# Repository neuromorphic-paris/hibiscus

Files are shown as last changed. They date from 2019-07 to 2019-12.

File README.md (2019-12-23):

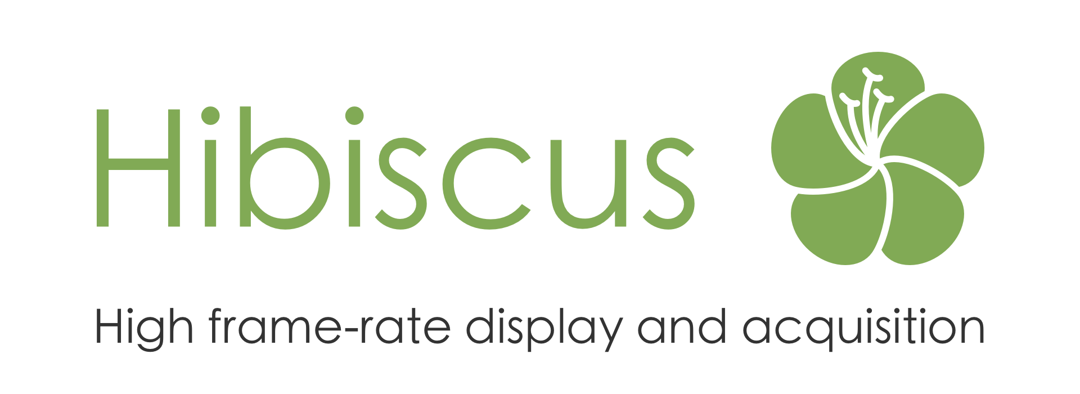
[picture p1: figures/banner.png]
banner


Hibiscus bundles tools to build a complete psychophysics platform on top of hummingbird. It is meant for a Jetson TX1 and a Teensy 3.5.

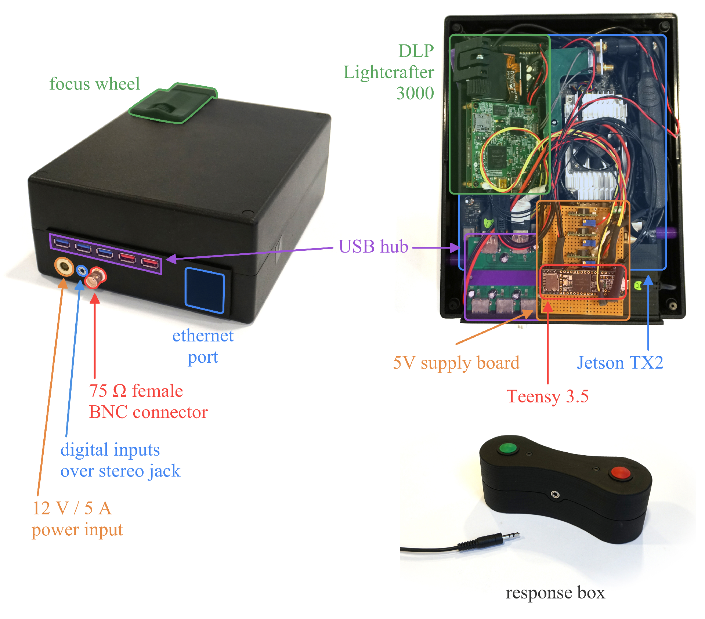
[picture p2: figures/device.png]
device


# parts

3D models of the Hibiscus components can be found in the *parts* directory, in STL format:
- *parts/box/* contains 3D models of the printable components required to assemble an Hibiscus box, in STL format. *parts/box/box.step* contains the whole assembly, and can be used as a reference to assemble it.
- *parts/optical_plate/* contains 3D models of the components of a box-less Hibiscus system, designed to be placed on a metric optical plate. *parts/optical_plate/optical_plate.step* contains the whole assembly, and can be used as a reference to assemble it.
- *parts/response-box/* provides the 3D models of the response box. *parts/response_box/response_box.step* contains the whole assembly, and can be used as a reference to assemble it.

# connect to the Jetson

1. Set up your ethernet configuration as follows:
  - IP address: `20.20.20.100`
  - Mask: `255.255.255.0`
  - Gateway: leave blank

2. Run the command:
```
ssh nvidia@20.20.20.99
```
The password is `nvidia`.

If you are connected to the same WiFi network as the Jetson, you can use it as well.

# network overview

Once everything is set up, the system will have the following network configuration.

__WiFi__: The Jetson's WiFi uses the default configuration, and is used to connect to the internet for updates, git clones... The *System Settings app* can be used to connect to new networks.
- Typical network: `192.168.1.*`
- Jetson IP address: given by the WiFi router.

__Ethernet__: The Jetson's ethernet port is used to communicate with other computers during experiments.
- Network: `20.20.20.*` (mask `255.255.255.0`)
- Jetson IP address: `20.20.20.99`
- Network configuration for the experimentalist:
  - IP address: `20.20.20.100`
  - Mask: `255.255.255.0`

__LightCrafter__: The LightCrafter manages a pseudo-network when connected to the Jetson through USB. The default IP must be changed to avoid conflicts with the WiFi network.
- Network: `10.10.10.*` (mask `255.255.255.0`)
- Jetson IP address: `10.10.10.99`
- LightCrafter IP address: `10.10.10.100`

# user guide

## scripts

### do_block.py

`do_block.py` runs the `calibrate` and `record` programs.

```sh
cd /path/to/hummingbird
python3 scripts/do_block.py [options] /path/to/parameters.py
```
Available options:
- `-f`, `--force` overwrites the output file if they exist.
- `-s`, `--skip-calibration` skips the calibration and only records. The calibration file must have been generated beforehand.
- `-g`, `--gpu-message` does not hide the GPU messages.
- `-h`, `--help` shows the help message.

The programs `calibrate` and `record` must be compiled before using the script. Instructions are given by the [programs](#programs) section.

`/path/to/parameters.py` must have the following structure:
```json
{
    "calibration": "/path/to/calibration.json",
    "clips": ["/path/to/first/clip.mp4", "/path/to/second/clip.mp4"],
    "output": "/path/to/output.es",
    "before_fixation_duration": 1200,
    "fixation_duration": 1100,
    "after_fixation_duration": 200,
    "points": [
        [ 34,  34],
        [171,  34],
        [308,  34],
        [ 34, 171],
        [171, 171],
        [308, 171],
        [ 34, 308],
        [171, 308],
        [308, 308]
    ],
    "pattern": [,
        "   #   ",
        "   #   ",
        "   #   ",
        "#######",
        "   #   ",
        "   #   ",
        "   #   "
    ]
}
```

- `"calibration"` is the path to the output calibration file. If this path is not absolute, it is resolved relatively to `/path/to/parameters.py`. If this file already exists, the program stops unless the flag `--force` is added to the arguments.

- `"clips"` is a list of video clip paths. Each non-absolute path in this list is resolved relatively to `/path/to/parameters.py`. The list cannot be empty, but has otherwise no length restriction.

- `"output"` is the path to the output Event Stream file. If this path is not absolute, it is resolved relatively to `/path/to/parameters.py`. If this file already exists, the program stops unless the flag `--force` is added to the arguments.

See [calibrate](#calibrate) for details on the optional parameters `"before_fixation_duration"`, `"fixation_duration"`, `"after_fixation_duration"`, `"points"` and `"pattern"`.

### read_es.py

`read_es.py` reads the binary output of the `record` program (see below) and prints a text-based representation of the data.

```sh
cd /path/to/hummingbird
python3 scripts/read_es.py [options] /path/to/record/output.es
```
Available options:
- `-h`, `--help` shows the help message.

This script requires the python module `eventstream`. Install instructions are available at [https://github.com/neuromorphic-paris/utilities#python](https://github.com/neuromorphic-paris/utilities#python).

## programs

### calibrate

`calibrate` estimates the parameters of the Livetrack to DMD 4 x 4 calibration matrix.
```sh
cd /path/to/hummingbird
./build/release/calibrate [options] output.json
```
Available options:
- `-p parameters.json`, `--parameters parameters.json` sets the calibration parameters. If the parameter is option is not passed, the parameters default to the equivalent *parameters.json* file content:
  ```json
  {
      "before_fixation_duration": 1200,
      "fixation_duration": 1100,
      "after_fixation_duration": 200,
      "points": [
          [ 34,  34],
          [171,  34],
          [308,  34],
          [ 34, 171],
          [171, 171],
          [308, 171],
          [ 34, 308],
          [171, 308],
          [308, 308]
      ],
      "pattern": [
          "   #   ",
          "   #   ",
          "   #   ",
          "#######",
          "   #   ",
          "   #   ",
          "   #   "
      ]
  }
  ```
  Only fields different from the defaults need to be specified. The durations are expressed in milliseconds. There must be at least four points (results are more accurate with more points. The pattern must have an odd number of rows and columns, and must contain only `'#'` and `' '` characters (representing on and off pixels, respectively).
- `-i [ip]`, `--ip [ip]` sets the LightCrafter IP address (defaults to `"10.10.10.100"`).
- `-f`, `--force` overwrites the output file if it exists.
- `-h`, `--help` shows the help message.

The generated `output.json` file has the following structure:
```json
{
    "points": [
        [ 34,  34],
        [171,  34],
        [308,  34],
        [ 34, 171],
        [171, 171],
        [308, 171],
        [ 34, 308],
        [171, 308],
        [308, 308]
    ],
    "left": {
        "matrix": [
            -0.000500992,   0.00269572, -0.00103148,  274.081,
             -0.00058359,  -0.00140402,  0.00189917,  212.388,
             5.27852e-19, -8.10961e-19, 1.06127e-18, 0.273093,
             3.89546e-07,  7.84538e-07, 2.16504e-07, 0.458227
        ],
        "reprojection_errors": [
            3.63763,
            4.67781,
            9.13678,
             6.2297,
            9.15647,
            7.30571,
            8.89996,
            9.15647,
            9.15507
        ]
    },
    "right": {
        "matrix": [
             0.00021368,   0.00266984, -0.000797397,   292.963,
            -0.00191981, -0.000169172,  4.59669e-05,   10.0208,
            4.17353e-08,  3.80498e-08,  -4.9549e-06, -0.476671,
            6.41801e-08, -1.92392e-07,   1.7655e-08,  0.396832
        ],
        "reprojection_errors": [
            5.35004,
            3.27579,
            5.49818,
            2.27209,
             4.0961,
            2.70487,
            5.49482,
            5.49901,
            5.49899
        ]
    }
}
```
The reprojection errors are expressed in screen pixels.

### record

`record` plays a list of stimuli and records precise timings.
```sh
cd /path/to/hummingbird
./record [options] /path/to/calibration.json /path/to/first/clip.mp4 [/path/to/second/clip.mp4...] output.es
```
Available options:
- `-f`, `--force` overwrites the output file if it exists.
- `-d`, `--duration` sets the inhibition duration in microseconds (defaults to `500000`). Button pushes during this duration after a video start are not accounted for.
- `-b [frames], --buffer [frames]` sets the number of frames buffered (defaults to 64). The smaller the buffer, the smaller the delay between videos. However, small buffers increase the risk to miss frames.
- `-i [ip]`, `--ip [ip]` sets the LightCrafter IP address (defaults to `"10.10.10.100"`).
- `-h`, `--help` shows the help message.

The generated `output.es` file is an [Event Stream](https://github.com/neuromorphic-paris/event_stream) containing generic events. Each generic event's payload contains at least one byte encoding the type in ASCII. Some types are associated with more data, as follows:

- `bytes[0] == 'a'` (respectively `bytes[0] == 'b'`): left (respectively right) eye position, the following twenty-four bytes encode the eye position as double floats in screen coordinates, and the pupil's ellipse's major and minor axis as uint32 in camera pixels (with a `8192` scale factor):
  ```cpp
  x = double(byte[1]
      | (byte[2] << 8)
      | (byte[3] << 16)
      | (byte[4] << 24)
      | (byte[5] << 32)
      | (byte[6] << 40)
      | (byte[7] << 48)
      | (byte[8] << 56))
  y = double(byte[9]
      | (byte[10] << 8)
      | (byte[11] << 16)
      | (byte[12] << 24)
      | (byte[13] << 32)
      | (byte[14] << 40)
      | (byte[15] << 48)
      | (byte[16] << 56))
  major_axis = (byte[17] | (byte[18] << 8) | (byte[19] << 16) | (byte[20] << 24)) / 8192
  minor_axis = (byte[21] | (byte[22] << 8) | (byte[23] << 16) | (byte[24] << 24)) / 8192
  ```
- `bytes[0] == 'c'`: LiveTrack synchronisation linear interpolation executed, the following sixteen bytes encode `t` and `u` (respectively the Teensy and LiveTrack timestamps):
  ```cpp
  t = byte[1]
      | (byte[2] << 8)
      | (byte[3] << 16)
      | (byte[4] << 24)
      | (byte[5] << 32)
      | (byte[6] << 40)
      | (byte[7] << 48)
      | (byte[8] << 56)
  u = byte[9]
     | (byte[10] << 8)
     | (byte[11] << 16)
     | (byte[12] << 24)
     | (byte[13] << 32)
     | (byte[14] << 40)
     | (byte[15] << 48)
     | (byte[16] << 56)
  ```
  The LiveTrack timestamps are converted to Teensy timestamps at runtime. `c` events can be used after recording to achieve a better, offline reconstruction of the clock conversion.
- `bytes[0] == 'f'`: frame displayed, the following four bytes encode its index in the current clip:
  ```cpp
  index = byte[1] | (byte[2] << 8) | (byte[3] << 16) | (byte[4] << 24)
  ```
- `bytes[0] == 'l'`: left button pressed, no extra bytes.
- `bytes[0] == 'r'`: right button pressed, no extra bytes.
- `bytes[0] == 's'`: new clip start, the following four bytes encode its index:
:
  ```cpp
  index = byte[1] | (byte[2] << 8) | (byte[3] << 16) | (byte[4] << 24)
  ```
- `bytes[0] == 'w'`: warning, the extra bytes encode the error message in ASCII.

### monitor_teensy

`monitor_teensy` displays the events timestamped by the teensy. It is meant as a debug tool to make sure that everything is properly connected.

```sh
cd /path/to/hummingbird
./build/release/monitor_teensy
```

# setup an out-of-the-box Jetson TX1

1. connect a screen, keyboard and mouse to the Jetson board. The LightCrafter can be used as a screen.

2. flash the Jetson TX1 with the latest release available (see https://developer.nvidia.com/embedded/linux-tegra-archive). The __L4T 28.2__ was used here. This step requires a Linux computer. The following commands were used on a Debian 9 machine (with *sudo* installed):
```sh
L4T_RELEASE_PACKAGE=Tegra210_Linux_R28.2.0_aarch64.tbz2
SAMPLE_FS_PACKAGE=Tegra_Linux_Sample-Root-Filesystem_R28.2.0_aarch64.tbz2
wget https://developer.nvidia.com/embedded/dlc/l4t-jetson-tx1-driver-package-28-2-ga -O ${L4T_RELEASE_PACKAGE}
wget https://developer.nvidia.com/embedded/dlc/l4t-sample-root-filesystem-28-2-ga -O ${SAMPLE_FS_PACKAGE}
sudo tar xpf ${L4T_RELEASE_PACKAGE}
cd Linux_for_Tegra/rootfs/
sudo tar xpf ../../${SAMPLE_FS_PACKAGE}
cd ..
sudo ./apply_binaries.sh
```
Then (from the Quick Start Guide):
    -  Ensure your Linux host system is connected to the Jetson Developer Kit's
      micro-USB port using a USB cable.
    - Put your Jetson Developer Kit into "USB Recovery Mode" (RCM). In all
      cases, press and hold the "REC" (force recovery) button for the duration
      of this step. Then, if your Jetson Developer Kit is powered off, press
      and release the "POWERBTN" button, or if your Jetson Developer Kit is
      already powered on, press and release the "RST" (reset) button. Finally,
      release the "REC" button.
    - Install (flash) the L4T release onto the Jetson Developer Kit, by
      executing the following command on your Linux host system:
    ```
    sudo ./flash.sh jetson-tx1 mmcblk0p1
    ```
If the error `/dev/loop0 is not block device` is encountered when flashing, run `sudo losetup --find` and retry.

3. all the following steps apply to the Jetson board. Log in with:
```
login: nvidia
password: nvidia
```

4. with the *System Settings* app:
  - (optionnal) change the keyboard map (*Keyboard* section)
  - setup the Wi-Fi connection (*Network* section)
  - prevent the screen from turning off (*Brightness & Lock* section)
  - switch to automatic login on boot for the *nvidia* user (*User accounts* section)
  - auto-hide the side bar (*Appearance* section, *Behavior* tab)

5. enable the *universe* packages by uncommenting the four lines 17 to 20 in */etc/apt/sources.list*
```
sudo gedit /etc/apt/sources.list
```

6. upgrade the packages
```sh
sudo apt update
sudo apt upgrade
sudo apt autoremove
```

7. enable the network time synchronization
  - Install the background synchronization manager
```sh
sudo apt install ntp
```
  - Edit */etc/ntp.conf*
```
sudo gedit /etc/ntp.conf
```
Add the following lines at the beginning of the file:
```
tinker panic 0
server 134.157.180.254
```
  - Reboot
  ```
  sudo reboot
  ```

8. install *hummingbird*'s C++ apps dependencies, and build them:
```sh
cd ~
# copy the hibiscus directory (manual copy for  now, git clone eventually)
cd hibiscus/third_party/hummingbird
sudo apt install premake4
sudo apt install ffmpeg
sudo apt install libgstreamermm-1.0-dev gstreamer1.0-plugins-good gstreamer1.0-plugins-bad gstreamer1.0-libav
sudo apt install libglfw3-dev
premake4 gmake
cd build
make
```

9. change the LightCrafter IP address:
  - Connect the LightCrafter's USB cable
  - Click on the WiFi icon in the top bar, and select connection information. Find the LightCrafter current IP address (here, the LightCrafter appears as *Wired Connection 2*, the Jetson has the address `192.168.1.99`, and the LightCrafter answers to ping at `192.168.1.100`)
  - Use the `change_lightcrafter_ip` app to switch the IP to `10.10.10.100`:
```sh
~/hibiscus/third_party/hummingbird/build/release/change_lightcrafter_ip 192.168.1.100 10.10.10.100
```
  - Restart the LightCrafter

10. enable the DMD display for distant sessions by appending to *~/.bashrc*:
```
export DISPLAY=:0.0
```

11. play *test.mp4* to check the installation
```sh
~/hibiscus/third_party/hummingbird/build/release/play -l ~/hibiscus/test.mp4
```
Press `Escape` to quit the app. The command prints debug information to *stderr*. We could not find an easy solution to disable it. A (bad) solution consists in filtering the output with bash, which can be done as follows:
```
{ ~/hibiscus/third_party/hummingbird/build/release/play -l ~/hibiscus/test.mp4 2>&1 1>&3 | grep -vE '(TVMR|NvMMLite|OPENMAX|Allocating)' 1>&2; } 3>&1
```
If you interrupt the app with `Ctrl` `C`, the LightCrafter will remain in high-speed mode. You can run:
```sh
~/hibiscus/third_party/hummingbird/build/release/change_lightcrafter_ip 10.10.10.100 10.10.10.100
```
to manually switch back to default mode. You can also install xdotool:
```sh
sudo apt install xdotool
```
and send an fake Escape keypress to the application from another terminal session:
```sh
xdotool key Escape
```

12. install the code dependencies [Eigen](http://eigen.tuxfamily.org) and [ncurses](https://www.gnu.org/software/ncurses):
```
sudo apt install libeigen3-dev libncursesw5-dev libv4l-dev libjpeg-dev libudev-dev
```

13. replace the content of */etc/network/interfaces* with:
```
source-directory /etc/network/interfaces.d
auto eth0
iface eth0 inet static
address 20.20.20.99
netmask 255.255.255.0
```

14. remove the Chromium desktop icon by appending to *~/.bashrc*:
```
rm -f ~/Desktop/chromium-browser.desktop
```

15. enable non-root access to the Teensy
```sh
sudo usermod -a -G dialout nvidia
```

16. add a udev rule to allow non-root users to read data from the LiveTrack:
```sh
printf 'SUBSYSTEMS=="usb", ATTRS{idVendor}=="0861", ATTRS{idProduct}=="3437", MODE="0660" GROUP="nvidia"\n' | sudo tee '/etc/udev/rules.d/99-livetrack.rules'
```

17. change the wallpaper and disable the file browser auto-open on USB mount:
```sh
sudo gsettings set org.gnome.desktop.background picture-uri file:///home/nvidia/hibiscus/wallpaper.png
sudo sudo gsettings set org.gnome.desktop.media-handling automount-open false
sudo reboot
```

18. install the `eventstream` python module:
```sh
pip3 install numpy
git clone --recursive https://github.com/neuromorphic-paris/utilities.git
cd utilities/bindings/python
python3 setup.py install
```

19. add exFAT support:
```sh
sudo apt install exfat-fuse
sudo apt install exfat-utils
```

20. allow non-root to set the date by adding `nvidia ALL=(ALL) NOPASSWD: /bin/date` to the sudoers configuration
```
sudo visudo
```

# teensy

Hummingbird uses a Teensy 3.5 board. It is responsible for precisely timestamping BNC, DMD and button events, as well as for booting the Jetson on power up. Its pinout is available [here](https://www.pjrc.com/teensy/pinout.html).

## setup

Install the [Arduino Software](https://www.arduino.cc/en/Main/Software) and its [Teensyduino](https://www.pjrc.com/teensy/teensyduino.html) extension. Flash the Teensy 3.5 board with *hibiscus/teensy/teensy.ino*.

## communication protocol

Messages in both directions start with `0x00`. Other instances of `0x00` are escaped, therefore `0x00` always indicates a message start. Likewise, `0xff` indicates a message end.

### jetson to teensy

- Request BNC rise: `0x00 'a' 0xff`
- Request BNC fall: `0x00 'b' 0xff`
- Reset: `0x00 'r' 0xff`

Reset empties the teensy's event fifos.

### teensy to jetson

- BNC rising edge: `0x00 'a' t[0] t[1] t[2] t[3] 0xff`
- BNC falling edge: `0x00 'b' t[0] t[1] t[2] t[3] 0xff`
- DMD half-frame: `0x00 'c' u[0] u[1] u[2] u[3] 0xff`
- DMD trigger rising edge (60 Hz frame boundary): `0x00 'd' t[0] t[1] t[2] t[3] 0xff`
- DMD trigger rising edge (others): `0x00 'e' t[0] t[1] t[2] t[3] 0xff`
- Main loop flush : `0x00 'f' t[0] t[1] t[2] t[3] 0xff`
- Left button pressed: `0x00 'l' t[0] t[1] t[2] t[3] 0xff`
- Right button pressed: `0x00 'r' t[0] t[1] t[2] t[3] 0xff`

`t` is the Arduino's clock time in microseconds (`micros()` output). `u` is the Teensy's tick index.

- if `message[i] == 0x00`, `message[i]` must be replaced with the two bytes `0xaa 0xab`
- if `message[i] == 0xaa`, `message[i]` must be replaced with the two bytes `0xaa 0xac`
- if `message[i] == 0xff`, `message[i]` must be replaced with the two bytes `0xaa 0xad`

Timestamps associated with the observables `d`, `e`, `l` and `r` may be out of order (though ordering is guaranteed between events of the same observable). However, no message sent after a flush message can have a timestamp prior to that flush message's.

# development dependencies

## Debian / Ubuntu

Open a terminal and run:
```sh
sudo apt install premake4 # cross-platform build configuration
sudo apt install clang-format # formatting tool
```

## macOS

Open a terminal and run:
```sh
brew install premake # cross-platform build configuration
brew install clang-format # formatting tool
```

## Windows

Download and install:
- [Visual Studio Community](https://visualstudio.microsoft.com/vs/community/). Select at least __Desktop development with C++__ when asked.
- [git](https://git-scm.com)
- [premake 4.x](https://premake.github.io/download.html). In order to use it from the command line, the *premake4.exe* executable must be copied to a directory in your path. After downloading and decompressing *premake-4.4-beta5-windows.zip*, run from the command line:
```sh
copy "%userprofile%\Downloads\premake-4.4-beta5-windows\premake4.exe" "%userprofile%\AppData\Local\Microsoft\WindowsApps"
```

After changing the code, format the source files by running from the *hibiscus* directory:
```sh
for file in source/*.hpp; do clang-format -i $file; done;
for file in source/*.cpp; do clang-format -i $file; done;
clang-format -i teensy/teensy.ino
```

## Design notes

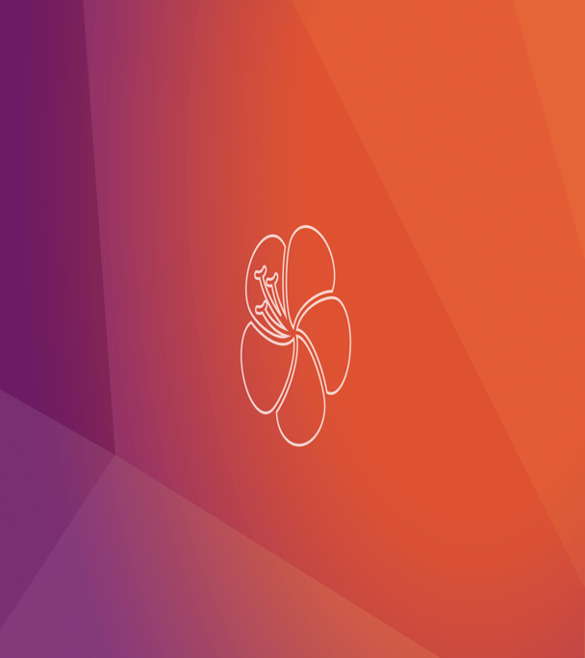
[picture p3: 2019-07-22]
wallpaper.png

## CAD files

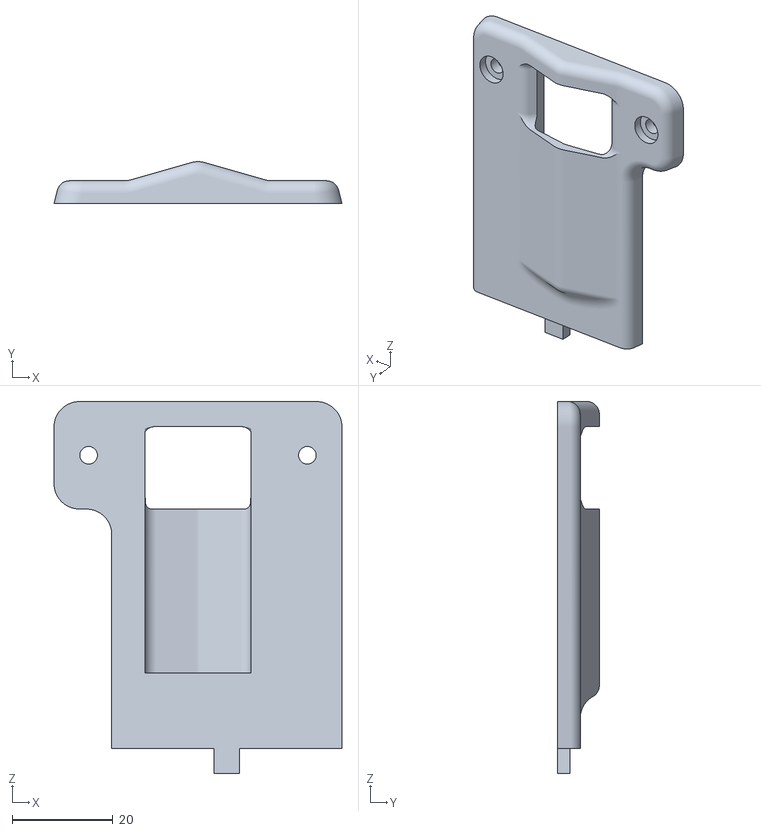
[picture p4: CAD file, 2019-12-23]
parts/box/guard.stl
57.3 x 8.30 x 74.0

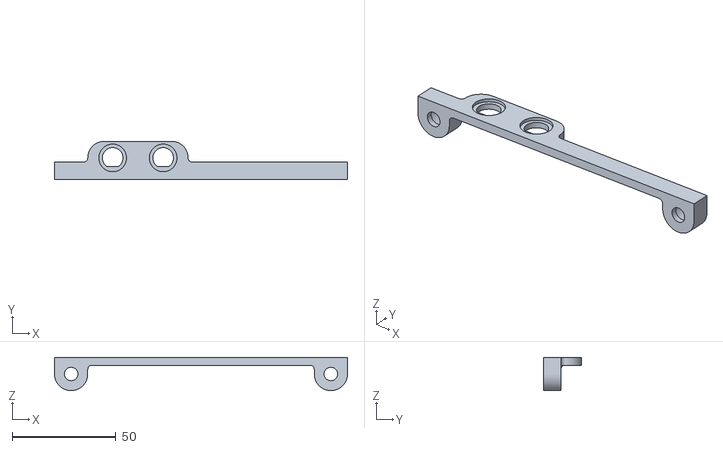
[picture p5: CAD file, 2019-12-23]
parts/optical_plate/bnc_panel.stl
141.0 x 18.5 x 16.0

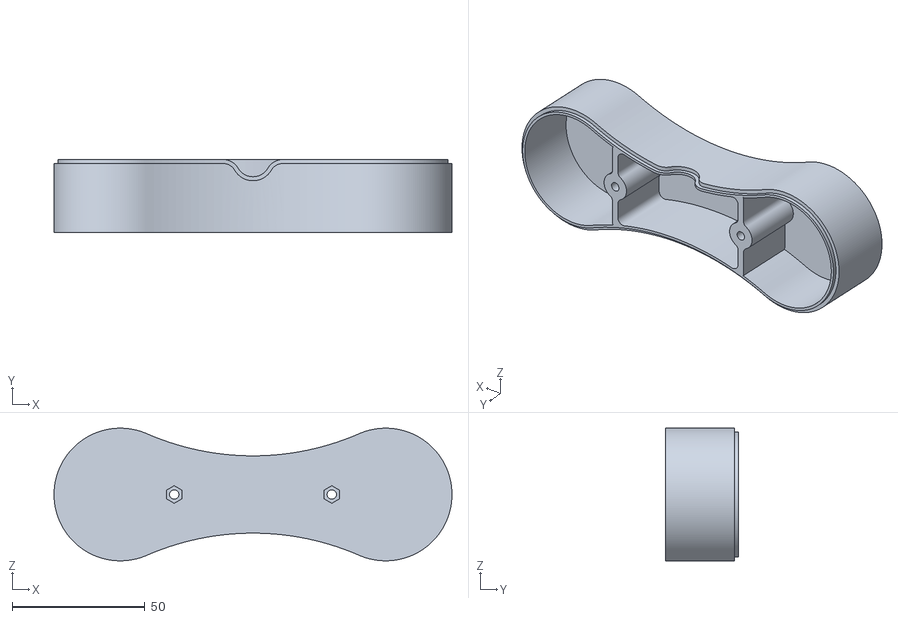
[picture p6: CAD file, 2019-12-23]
parts/response_box/bottom.stl
150.0 x 27.5 x 50.0

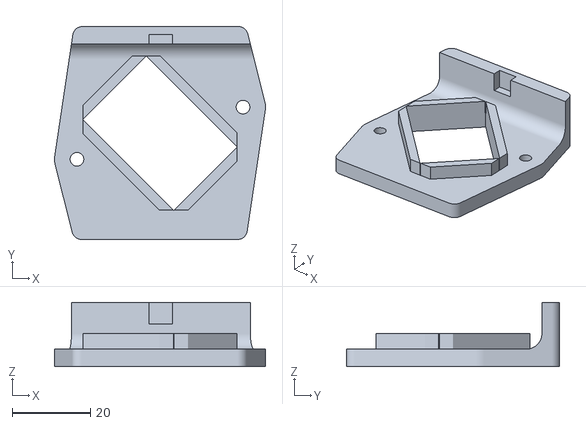
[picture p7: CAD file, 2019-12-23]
parts/box/window.stl
54.0 x 54.5 x 16.5

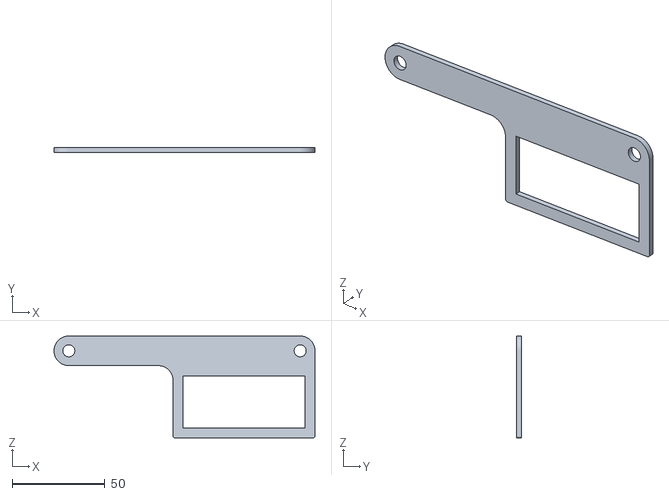
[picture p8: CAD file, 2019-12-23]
parts/optical_plate/teensy_top.stl
141.0 x 2.50 x 55.1

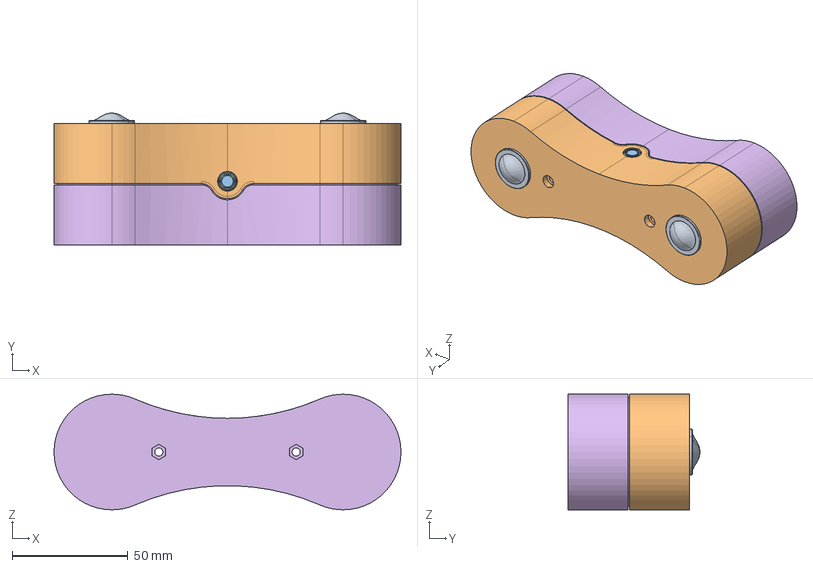
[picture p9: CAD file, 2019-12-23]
parts/response_box/response_box.step
150.0 x 57.0 x 50.0 mm
button x 2
top
jack
jack_nut
button_nut x 2
bottom

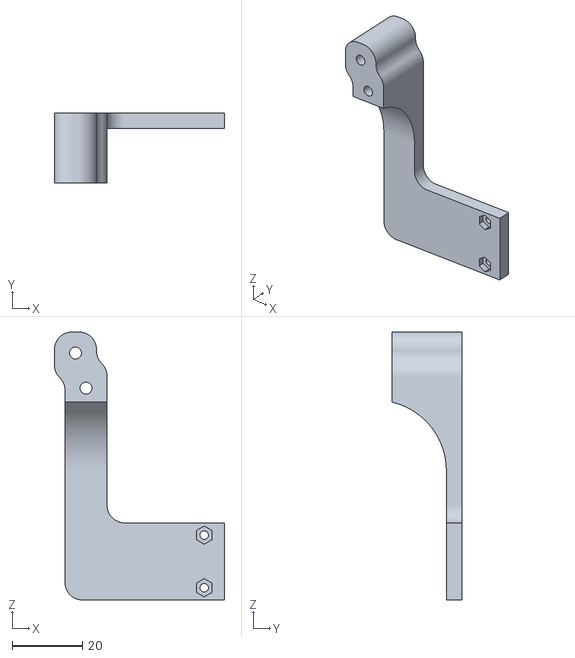
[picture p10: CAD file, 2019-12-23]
parts/box/antenna_holder.stl
48.5 x 20.0 x 76.4

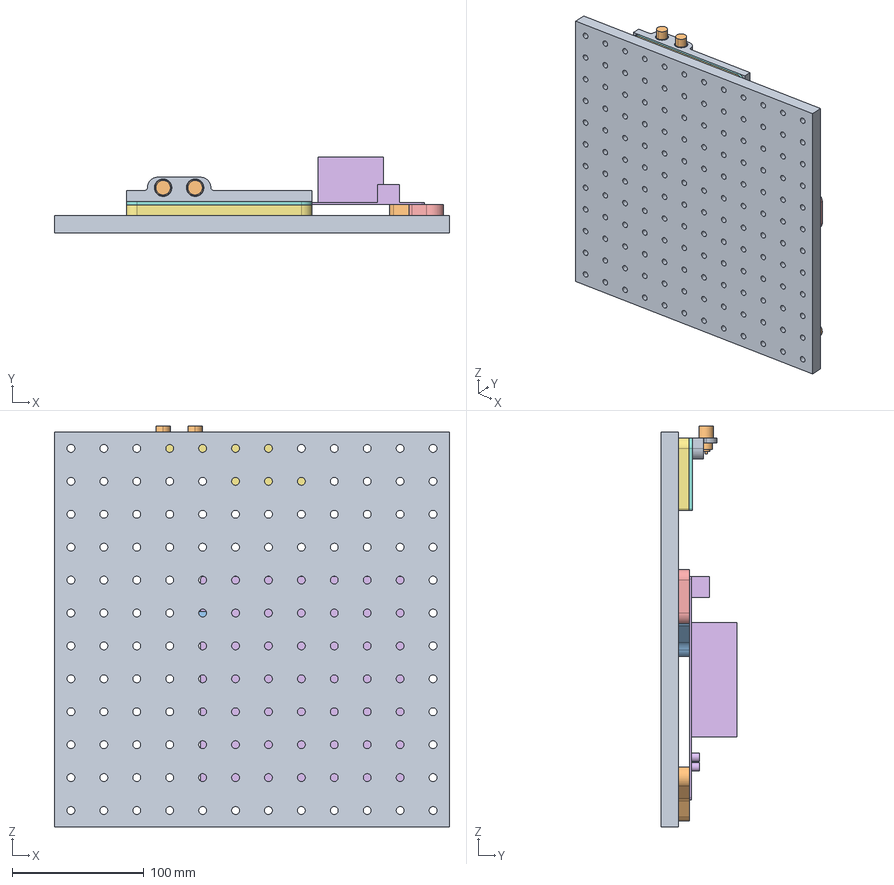
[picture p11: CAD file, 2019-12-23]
parts/optical_plate/optical_plate.step
300.0 x 57.5 x 304.5 mm
plate
adapter
jetson
teensy_base
teensy_top
bnc_panel
bnc x 2

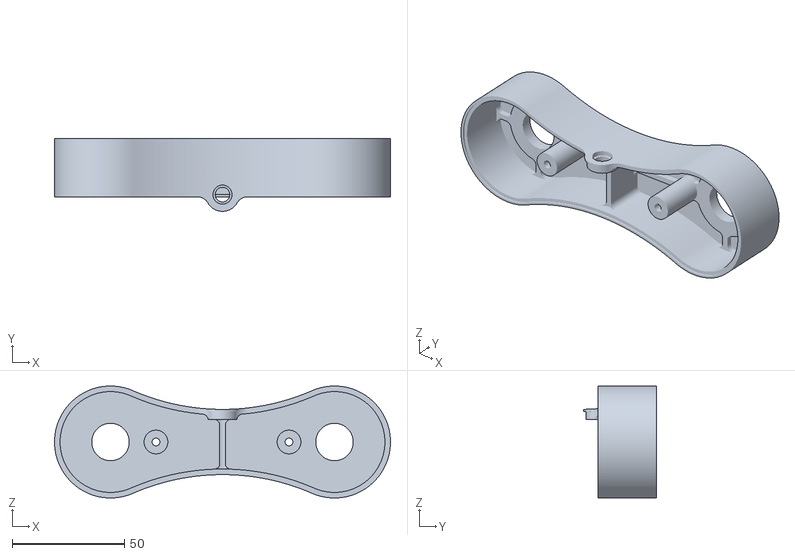
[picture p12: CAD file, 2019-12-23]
parts/response_box/top.stl
150.0 x 32.5 x 50.0

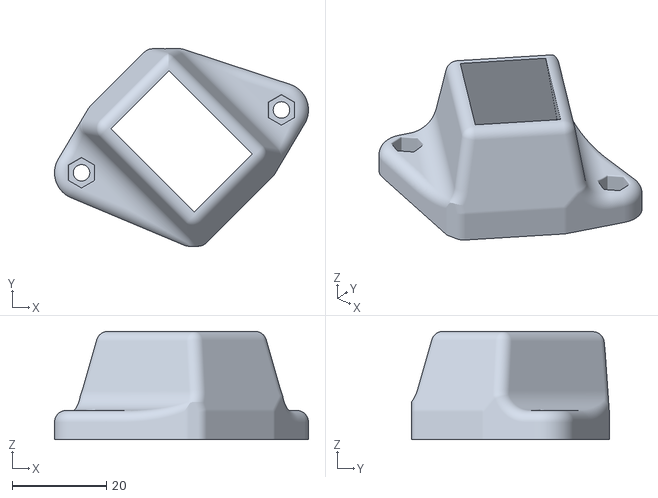
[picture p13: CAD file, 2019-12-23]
parts/box/cone.stl
54.0 x 42.0 x 23.0

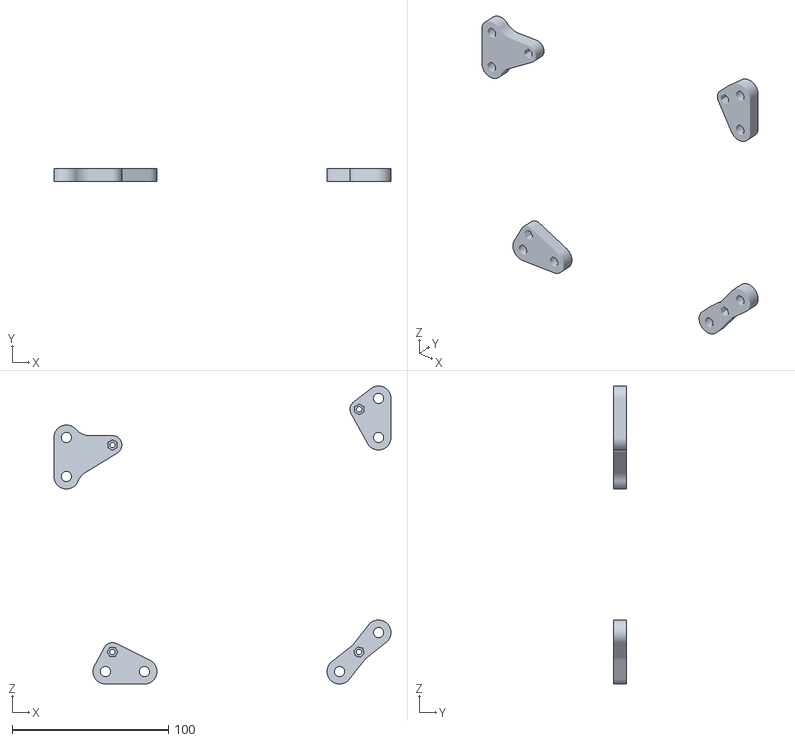
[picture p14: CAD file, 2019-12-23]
parts/optical_plate/adapter.stl
216.0 x 8.50 x 191.0

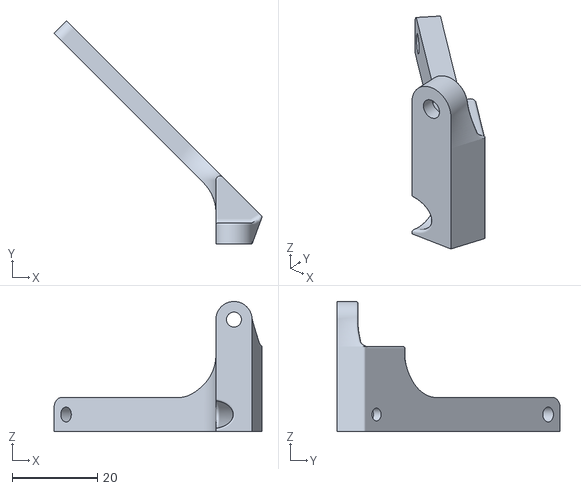
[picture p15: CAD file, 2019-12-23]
parts/box/small_45.stl
48.9 x 52.5 x 30.5

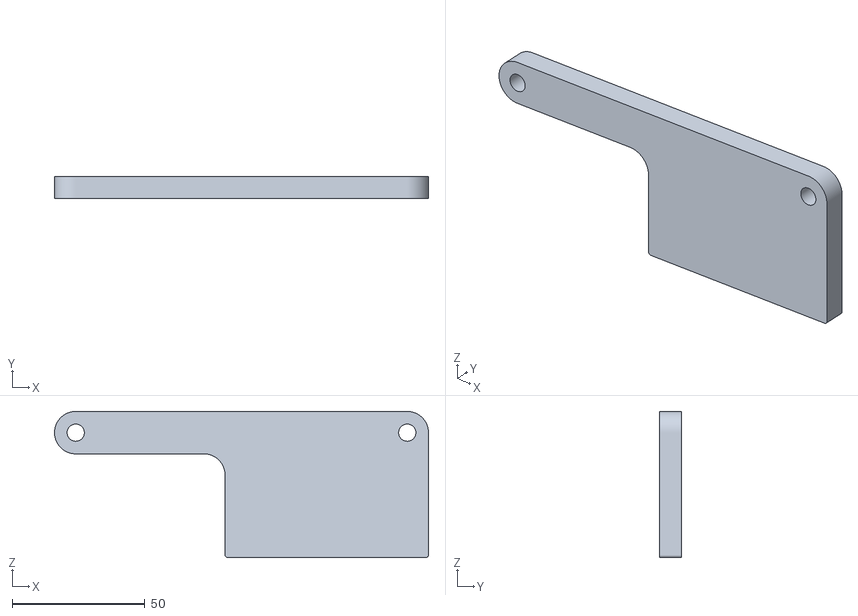
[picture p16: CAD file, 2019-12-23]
parts/optical_plate/teensy_base.stl
141.0 x 8.30 x 55.1

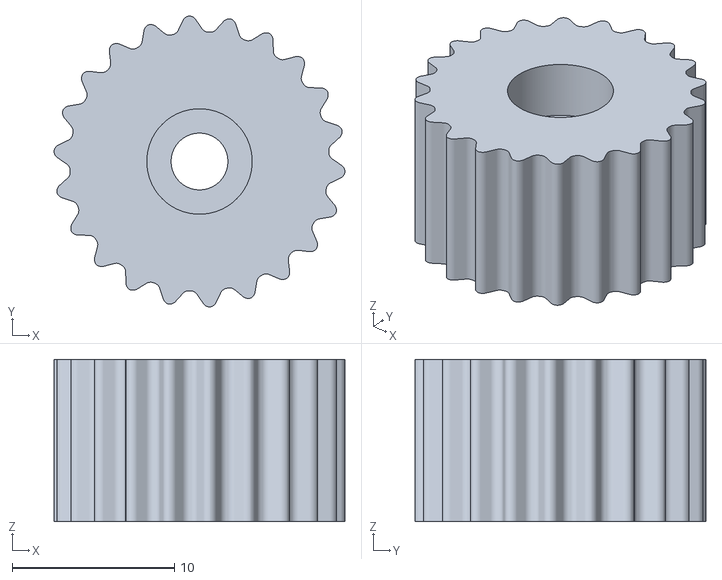
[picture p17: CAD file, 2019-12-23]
parts/box/wheel.stl
18.0 x 18.0 x 10.0

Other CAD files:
parts/box/ethernet.stl
parts/box/slider.stl
parts/box/antenna_spacer.stl
parts/box/chassis.stl
parts/box/large_washer_moon.stl
parts/box/teensee_holder.stl
parts/box/thick_washer_0.stl
parts/box/thick_washer_1.stl
parts/box/thick_washer_2.stl
parts/box/washer.stl

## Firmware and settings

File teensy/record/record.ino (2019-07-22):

const byte bnc_pin = 37;
const byte dmd_pin = 22;
const byte jack_l_pin = 2;
const byte jack_r_pin = 3;
const byte jetson_up_pin = 28;
const byte jetson_switch_on_pin = 29;
const byte led_pin = 13;
const uint32_t tick_half_period = 8333;

/// input represents a signal to watch and timestamp.
struct input {
    const byte id;
    const byte pin;
    const uint32_t debounce_t;
    void (*interrupt_callback)();
    uint8_t tail;
    volatile uint32_t change_t;
    volatile bool is_high;
    volatile uint8_t head;
    volatile uint32_t ts[256];
};

/// interrupt_callback is called whenever the input changes.
/// rising edge changes are notified to the main loop.
void interrupt_callback(input* updated_input) {
    const volatile uint32_t interrupt_t = micros();
    if (updated_input->is_high != (digitalRead(updated_input->pin) == HIGH)) {
        if (updated_input->is_high) {
            updated_input->is_high = false;
        } else {
            updated_input->is_high = true;
            if (interrupt_t - updated_input->change_t > updated_input->debounce_t) {
                updated_input->ts[updated_input->head] = interrupt_t;
                ++updated_input->head;
            }
        }
        updated_input->change_t = interrupt_t;
    }
}

/// inputs lists the input signals.
/// the character 'c' is reserved for clock messages.
input inputs[] = {
    {'d', dmd_pin, 0, d_callback},         // dmd
    {'l', jack_l_pin, 100000, l_callback}, // red button (left)
    {'r', jack_r_pin, 100000, r_callback}, // green button (right)
};
void d_callback() {
    interrupt_callback(&inputs[0]);
}
void l_callback() {
    interrupt_callback(&inputs[1]);
}
void r_callback() {
    interrupt_callback(&inputs[2]);
}

/// read_state stores the globals used by the read function.
struct read_state {
    byte* message;
    const uint32_t message_size;
    uint32_t index;
    bool reading;
    bool escaped;
};

/// read tries to consume a Serial byte and returns true if a new message is ready.
bool read(struct read_state* state) {
    if (Serial.available() > 0) {
        const byte read_byte = Serial.read();
        if (state->reading) {
            byte interpreted_byte;
            bool byte_available = false;
            if (state->escaped) {
                state->escaped = false;
                switch (read_byte) {
                    case 0xab:
                        interpreted_byte = 0x00;
                        byte_available = true;
                        break;
                    case 0xac:
                        interpreted_byte = 0xaa;
                        byte_available = true;
                        break;
                    case 0xad:
                        interpreted_byte = 0xff;
                        byte_available = true;
                        break;
                    default:
                        state->reading = false;
                }
            } else {
                switch (read_byte) {
                    case 0x00:
                        state->index = 0;
                        break;
                    case 0xaa:
                        state->escaped = true;
                        break;
                    case 0xff:
                        state->reading = false;
                        return true;
                    default:
                        interpreted_byte = read_byte;
                        byte_available = true;
                }
            }
            if (byte_available) {
                if (state->index < state->message_size) {
                    state->message[state->index] = interpreted_byte;
                    ++(state->index);
                } else {
                    state->reading = false;
                }
            }
        } else if (read_byte == 0x00) {
            state->reading = true;
            state->escaped = false;
            state->index = 0;
        }
    }
    return false;
}

/// write escapes and writes a null-terminated message to the serial.
void write(const byte* message, const uint32_t size, const bool flush) {
    Serial.write(0x00);
    for (uint8_t index = 0; index < size; ++index) {
        switch (message[index]) {
            case 0x00:
                Serial.write(0xaa);
                Serial.write(0xab);
                break;
            case 0xaa:
                Serial.write(0xaa);
                Serial.write(0xac);
                break;
            case 0xff:
                Serial.write(0xaa);
                Serial.write(0xad);
                break;
            default:
                Serial.write(message[index]);
        }
    }
    Serial.write(0xff);
    if (flush) {
        Serial.send_now();
    }
}

/// send generates and writes a message.
void send(const byte type, const uint32_t t, const bool flush) {
    byte message[5] = {
        type, (byte)(t & 0xff), (byte)((t >> 8) & 0xff), (byte)((t >> 16) & 0xff), (byte)((t >> 24) & 0xff)};
    write(message, sizeof(message), flush);
}

/// state variables
byte read_message[1];
read_state state = {read_message, sizeof(read_message), 0, false, false};
uint32_t previous_d_t = 0;
bool frame_boundary = false;
uint32_t tick = 0;
uint32_t tick_t = 0;
bool ticked = false;
uint32_t previous_flush_t = 0;
uint32_t computer_tick = 0;
bool pinged = false;
bool send_fake_event = false;

void setup() {
    // setup pins
    pinMode(jetson_up_pin, INPUT);
    pinMode(jetson_switch_on_pin, OUTPUT);
    pinMode(led_pin, OUTPUT);
    digitalWrite(led_pin, LOW);
    pinMode(bnc_pin, OUTPUT);
    digitalWrite(bnc_pin, LOW);

    // boot the jetson
    digitalWrite(jetson_switch_on_pin, HIGH);
    if (digitalRead(jetson_up_pin) == LOW) {
        delay(500);
        digitalWrite(jetson_switch_on_pin, LOW);
        while (digitalRead(jetson_up_pin) == LOW) {
        }
        digitalWrite(jetson_switch_on_pin, HIGH);
    }

    // start the USB communication
    Serial.begin(9600);

    // initialize the observables
    for (unsigned int index = 0; index < sizeof(inputs) / sizeof(input); ++index) {
        pinMode(inputs[index].pin, INPUT);
        inputs[index].tail = 0;
        inputs[index].change_t = 0;
        inputs[index].is_high = false;
        inputs[index].head = 0;
        attachInterrupt(digitalPinToInterrupt(inputs[index].pin), inputs[index].interrupt_callback, CHANGE);
    }

    // switch on the board LED
    digitalWrite(led_pin, HIGH);
}

void loop() {
    const volatile uint32_t loop_t = micros();
    {
        bool has_message = false;
        for (unsigned int index = 0; index < sizeof(inputs) / sizeof(input); ++index) {
            const uint8_t local_head = inputs[index].head;
            while (inputs[index].tail != local_head) {
                has_message = true;
                const uint32_t local_t = inputs[index].ts[inputs[index].tail];
                if (inputs[index].id == 'd') {
                    const uint32_t delta_t = local_t - previous_d_t;
                    if (delta_t > 1030 - 100 && delta_t < 1030 + 100) {
                        send('e', local_t, false);
                        frame_boundary = true;
                    } else {
                        if (frame_boundary) {
                            send('d', local_t, false);
                            frame_boundary = false;
                            tick_t = local_t;
                            ticked = true;
                            ++tick;
                        } else {
                            send('e', local_t, false);
                        }
                    }
                    previous_d_t = local_t;
                } else {
                    send(inputs[index].id, local_t, false);
                }
                ++inputs[index].tail;
            }
        }
        if (send_fake_event) {
            send_fake_event = false;
            send(loop_t % 2 == 0 ? 'l' : 'r', loop_t, false);
        }
        if (has_message || loop_t - previous_flush_t > 100000) {
            send('f', loop_t, true);
            previous_flush_t = loop_t;
        }
    }
    if (ticked && (micros() - tick_t > tick_half_period)) {
        send('c', tick, true);
        ticked = false;
    }
    if (read(&state)) {
        if (state.index == 1) {
            switch (state.message[0]) {
                case 'a':
                case 'b': {
                    digitalWrite(bnc_pin, state.message[0] == 'a' ? HIGH : LOW);
                    const uint32_t now = micros();
                    send(state.message[0], now, true);
                    break;
                }
                case 'r': {
                    digitalWrite(bnc_pin, LOW);
                    previous_d_t = 0;
                    tick = 0;
                    tick_t = 0;
                    ticked = false;
                    previous_flush_t = 0;
                    computer_tick = 0;
                    pinged = false;
                    noInterrupts();
                    for (unsigned int index = 0; index < sizeof(inputs) / sizeof(input); ++index) {
                        inputs[index].tail = inputs[index].head;
                    }
                    byte message[1] = {'r'};
                    write(message, sizeof(message), true);
                    interrupts();
                    break;
                }
                case 'f': {
                    send_fake_event = true;
                    break;
                }
                default:
                    break;
            }
        }
    }
}

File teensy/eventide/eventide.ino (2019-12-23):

const byte bnc_pin = 37;
const byte led_pin = 13;
const byte dmd_pin = 23;

/// serial_state contains the state parameters for the software serial reader.
struct serial_state {
    const byte pin;
    const uint32_t start_offset;
    const uint32_t tick_duration;
    byte code;
    uint32_t start_t;
    byte value;
    byte value_index;
};

/// read_serial must be called by the main loop.
/// true is returned if a new byte is available on the input serial.
bool read_serial(const uint32_t now, byte* value, serial_state* state) {
    switch (state->code) {
        case 0: {
            if (digitalReadFast(state->pin) == LOW) {
                state->code = 1;
                state->start_t = now;
                state->value = 0;
                state->value_index = 0;
            }
            break;
        }
        case 1: {
            if (now - state->start_t
                >= (uint32_t)state->start_offset + (uint32_t)state->value_index * (uint32_t)state->tick_duration) {
                if (digitalReadFast(state->pin) == HIGH) {
                    state->value |= (1 << state->value_index);
                }
                if (state->value_index == 7) {
                    state->code = 2;
                } else {
                    ++state->value_index;
                }
            }
            break;
        }
        case 2: {
            if (now - state->start_t >= (uint32_t)state->start_offset + 8u * (uint32_t)state->tick_duration) {
                if (digitalReadFast(state->pin) == HIGH) {
                    *value = state->value;
                    state->code = 0;
                    return true;
                } else {
                    state->code = 3;
                }
            }
            break;
        }
        case 3: {
            if (digitalReadFast(state->pin) == HIGH) {
                state->start_t = now;
                state->code = 4;
            }
            break;
        }
        case 4: {
            if (digitalReadFast(state->pin) == LOW) {
                state->code = 3;
            } else if (now - state->start_t >= (uint32_t)state->start_offset + 8u * (uint32_t)state->tick_duration) {
                state->code = 0;
            }
            break;
        }
        default: {
            state->code = 3;
            break;
        }
    }
    return false;
}

/// write escapes and writes a null-terminated message to the serial.
void write(const byte* message, const uint32_t size, const bool flush) {
    Serial.write(0x00);
    for (uint8_t index = 0; index < size; ++index) {
        switch (message[index]) {
            case 0x00:
                Serial.write(0xaa);
                Serial.write(0xab);
                break;
            case 0xaa:
                Serial.write(0xaa);
                Serial.write(0xac);
                break;
            case 0xff:
                Serial.write(0xaa);
                Serial.write(0xad);
                break;
            default:
                Serial.write(message[index]);
        }
    }
    Serial.write(0xff);
    if (flush) {
        Serial.send_now();
    }
}

/// cumulated_bits_to_message estimates the most likely message from the sent replicas.
byte cumulated_bits_to_message(const byte* cumulated_bits, const uint8_t threshold) {
    byte result = 0;
    for (uint8_t index = 0; index < 8; ++index) {
        if (cumulated_bits[index] >= threshold) {
            result |= (1 << index);
        }
    }
    return result;
}

/// state variables
serial_state state = {bnc_pin, (uint32_t)(1e6 / 9600 * 1.5), (uint32_t)(1e6 / 9600), 3, 0, 0, 0};
byte cumulated_bits[8] = {0, 0, 0, 0, 0, 0, 0, 0};
byte read_index = 0;
uint32_t previous_read_t = 0;

void setup() {
    pinMode(bnc_pin, INPUT);
    pinMode(led_pin, OUTPUT);
    pinMode(dmd_pin, OUTPUT);
    digitalWrite(led_pin, LOW);
    digitalWrite(dmd_pin, LOW);

    // start the USB communication
    Serial.begin(9600);

    digitalWrite(led_pin, HIGH);
}

void loop() {
    const uint32_t now = micros();
    byte read_byte;
    if (read_serial(now, &read_byte, &state)) {
        ++read_index;
        previous_read_t = now;
        for (uint8_t index = 0; index < 8; ++index) {
            if (((read_byte >> index) & 1) == 1) {
                ++cumulated_bits[index];
            }
        }
        if (read_index >= 5) {
            const byte message = cumulated_bits_to_message(cumulated_bits, (read_index + 1) / 2);
            write(&message, 1, true);
            read_index = 0;
            memset(cumulated_bits, 0, sizeof(cumulated_bits));
        }
    } else if (read_index > 0 && now - previous_read_t > 20000) {
        const byte message = cumulated_bits_to_message(cumulated_bits, (read_index + 1) / 2);
        write(&message, 1, true);
        read_index = 0;
        memset(cumulated_bits, 0, sizeof(cumulated_bits));
    }
}

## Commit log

2019-12-23 Add the 3D printed parts
    [adapter.stl, antenna_holder.stl, antenna_spacer.stl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]
2019-12-23 Change the extension case
    [ethernet.stl, guard.stl, wheel.stl]
